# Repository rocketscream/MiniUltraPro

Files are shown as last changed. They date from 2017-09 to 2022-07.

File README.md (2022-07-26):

# Mini Ultra Pro
Mini Ultra Pro is an Arduino Compatible 32-bit ARM Cortex M0+ board that is suitable for ultra low power applications. During deep sleep mode, the board consumes only 16.5 uA (with the on-board serial flash chip and radio module in sleep mode). The board comes equipped with a 2Mbyte of serial flash and E19-900M20S2 LoRa radio module. Suitable application includes ultra low power wireless sensor network nodes that runs on Li-Ion/Pol batteries. On-board charger supports Li-Ion/Pol with proper load sharing capability to prolong the lifespan of the battery. The LoRa capable E19-900M20S2 radio module is able to achieve up to 8 km (in semi urban area, frequency of 915 MHz, transmission power of 20 dBm, LoRa spreading factor (SF) of 12, and coding rate (CR) of 4/5). A unique 64-bit MAC ID chip (Microchip's 24AA025E64) is available on-board to be used as DEVEUI in a LoRaWAN network.

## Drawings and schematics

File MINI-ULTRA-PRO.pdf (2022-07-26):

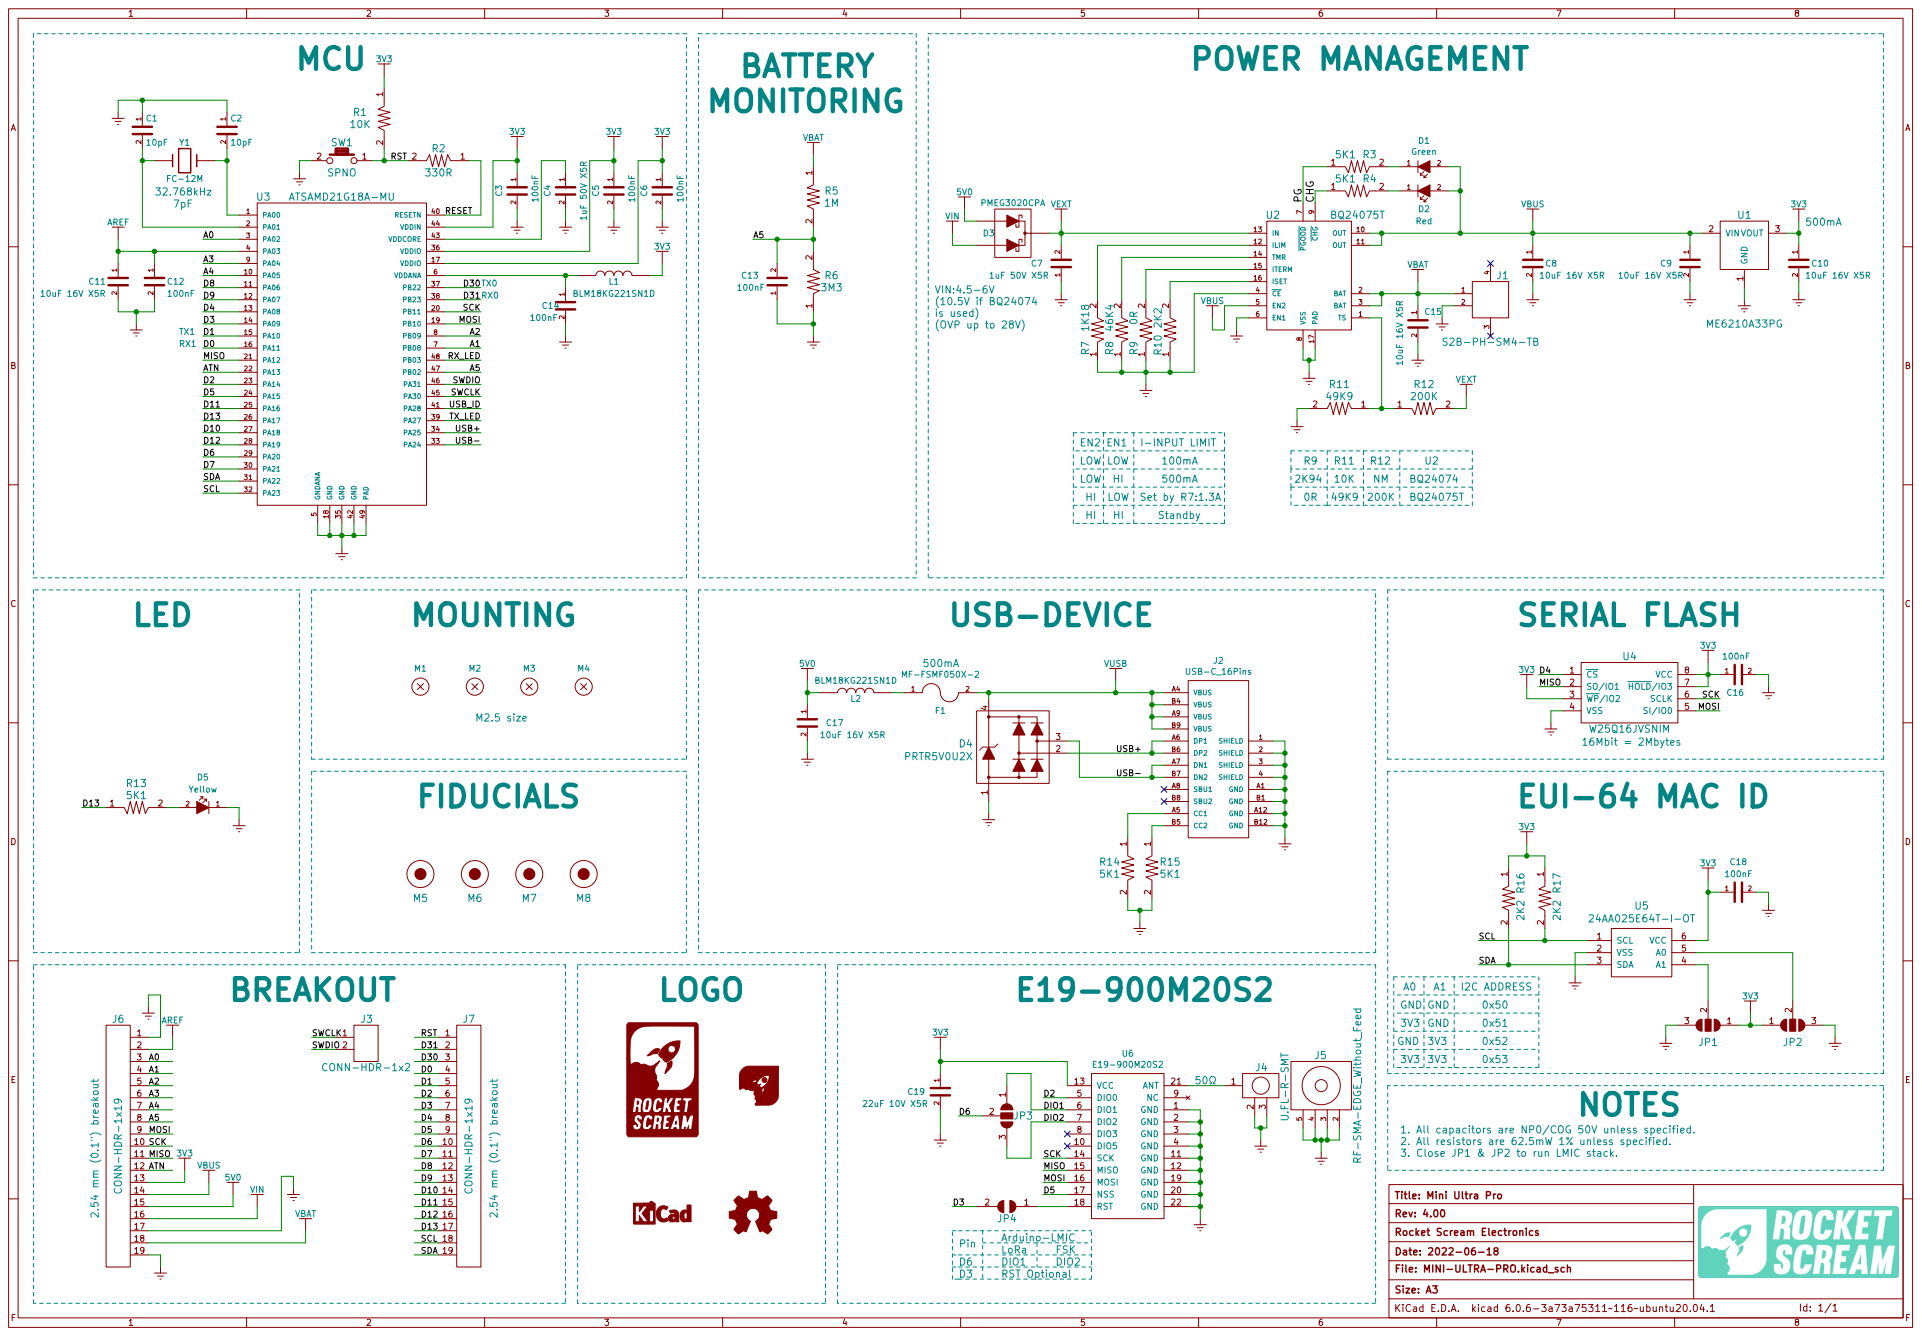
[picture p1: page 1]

1 2 C15 10uF 16V X5R TS 1 OUT 10 OUT 11 ILIM 12

A0 | GND

3V3 | | 0x51
3V3 GND | | 0x52

3. Close JP1 & JP2 to run LMIC stack. 3V3

1. All capacitors are NP0/COG 50V unless specified.
2. All resistors are 62.5mW 1% unless specified.

Id: 1/1 Title: Mini Ultra Pro
F Date: 2022-06-18 KiCad E.D.A. kicad 6.0.6-3a73a75311~116~ubuntu20.04.1 Rev: 4.00 Size: A3
File: MINI-ULTRA-PRO.kicad_sch Rocket Scream Electronics

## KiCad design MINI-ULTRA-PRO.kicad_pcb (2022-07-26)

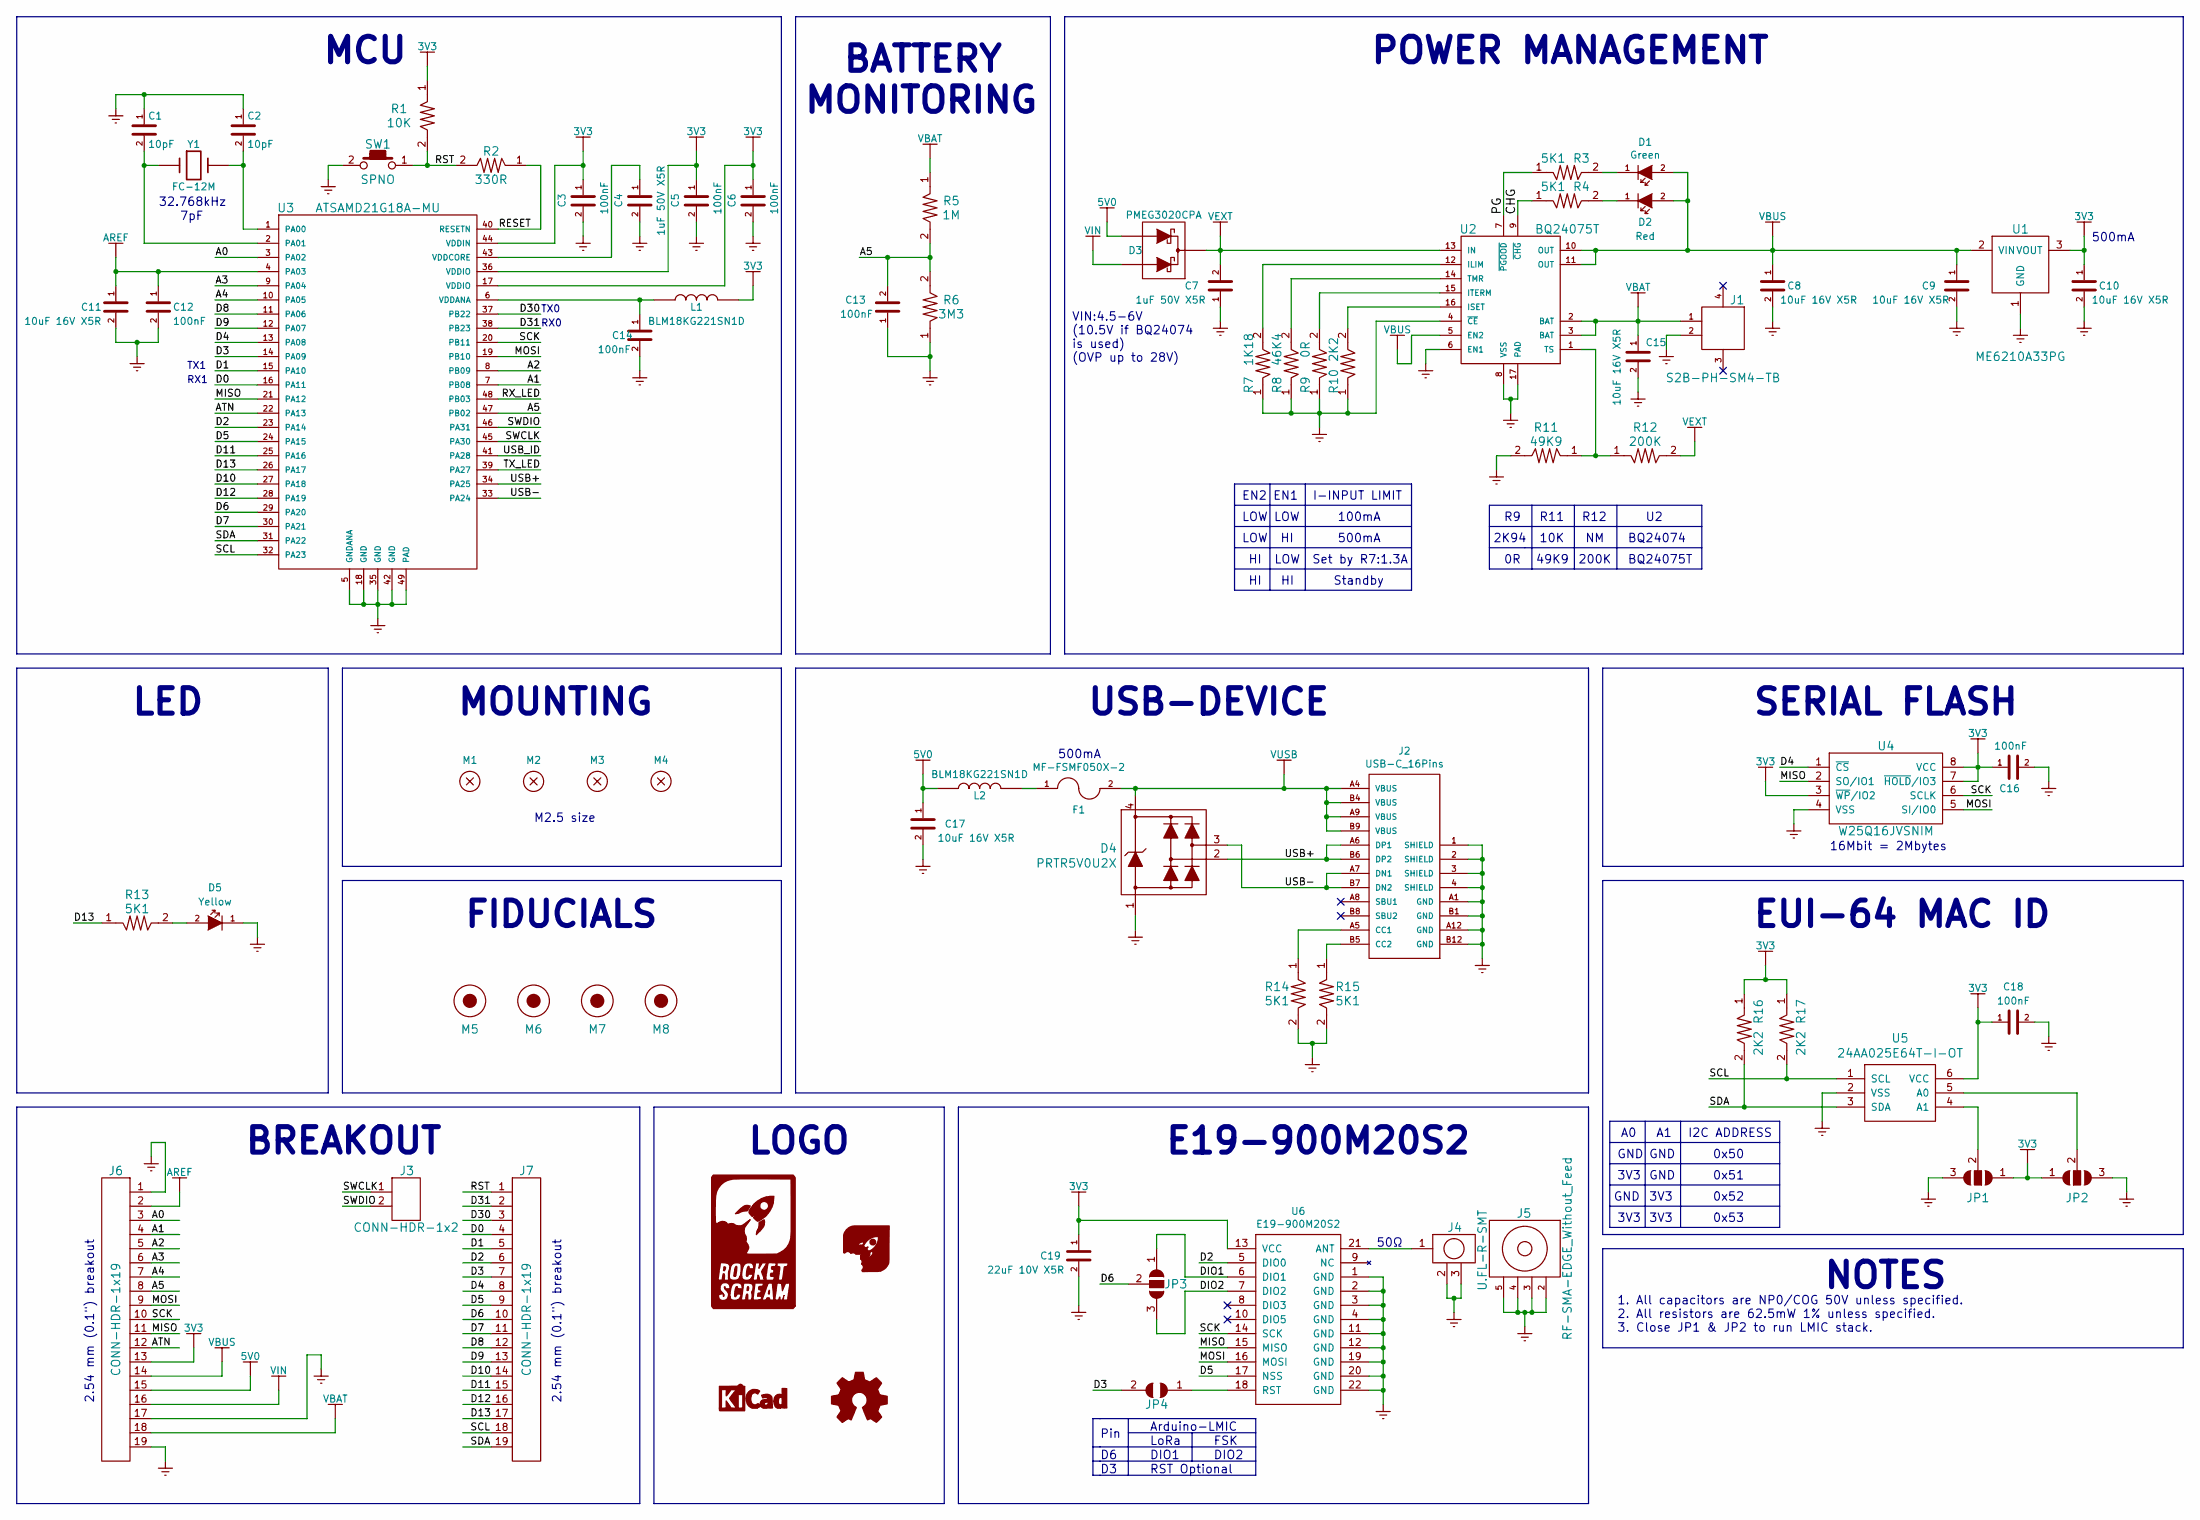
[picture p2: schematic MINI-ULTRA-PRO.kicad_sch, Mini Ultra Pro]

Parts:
C1, C2: 10pF; C_0603
C3, C5, C6, C12, C13, C14, C16, C18: 100nF; C_0603
C4, C7: 1uF 50V X5R; C_0603
C8, C9, C10, C11, C15, C17: 10uF 16V X5R; C_0603
C19: 22uF 10V X5R; C_0603
D1: Green; LED_0603
D2: Red; LED_0603
D3: PMEG3020CPA; SOT-1016
D4: PRTR5V0U2X; SOT-143B
D5: Yellow; LED_0603
F1: MF-FSMF050X-2; MF-FSMF
J1: S2B-PH-SM4-TB
J2: USB-C_16Pins; USB-TYPE-C-16PIN-SMD
J3: CONN-HDR-1x2; HDR_1x2_Pitch2.54mm_WithoutSilk
J4: U.FL-R-SMT; U.FL-R-SMT_Extended
J5: RF-SMA-EDGE_Without_Feed
J6, J7: CONN-HDR-1x19; HDR_1x19_Pitch2.54mm_WithoutSilk
JP1, JP2, JP3: JUMPER-2-WAY; JUMPER-2-WAY-SMD
JP4: JUMPER-1-WAY; JUMPER-1-WAY-SMD
L1, L2: BLM18KG221SN1D; I_0603
LOGO1: LOGO-ROCKET-SCREAM; LOGO-ROCKET-SCREAM_Vertical_Small
LOGO2: LOGO-ROCKET-SCREAM; LOGO-ROCKET-SCREAM_Without_Text_XXXSmall
LOGO3: LOGO-KICAD; LOGO-KICAD_XSmall
LOGO4: LOGO-OSHW; LOGO-OSHW_Small
M1, M2, M3, M4: MOUNT_HOLE; HOLE_NPTH_2.2MM
M5, M6, M7, M8: FIDUCIAL; FIDUCIAL-0.5MM_SQUARE
R1: 10K; R_0603
R2: 330R; R_0603
R3, R4, R13, R14, R15: 5K1; R_0603
R5: 1M; R_0603
R6: 3M3; R_0603
R7: 1K18; R_0603
R8: 46K4; R_0603
R9: 0R; R_0603
R10, R16, R17: 2K2; R_0603
R11: 49K9; R_0603
R12: 200K; R_0603
SW1: SPNO; TS-1086E-12
U1: ME6210A33PG; SOT-89_Microchip
U2: BQ24075T; QFN-16_3x3mm_TI
U3: ATSAMD21G18A-MU; QFN-48-1EP_7x7mm_Pitch0.5mm
U4: W25Q16JVSNIM; SOIC-8-N_8S1
U5: 24AA025E64T-I-OT; SOT-23-6
U6: E19-900M20S2
Y1: FC-12M; SC-20S

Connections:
3V3: C3.1, C5.1, C6.1, C10.1, C16.1, C18.1, C19.1, J6.13, JP1.1, JP2.1, L1.2, R1.1, R16.1, R17.1, U1.3 (VOUT), U3.17 (VDDIO), U3.36 (VDDIO), U3.44 (VDDIN), U4.3 (~WP/IO2), U4.7 (~HOLD/IO3), U4.8 (VCC), U5.6 (VCC), U6.13 (VCC)
5V0: C17.1, D3.1 (A), J6.15, L2.1
/A0: J6.3, U3.3 (PA02)
/A1: J6.4, U3.7 (PB08)
/A2: J6.5, U3.8 (PB09)
/A3: J6.6, U3.9 (PA04)
/A4: J6.7, U3.10 (PA05)
/A5: C13.2, J6.8, R5.2, R6.2, U3.47 (PB02)
/ATN: J6.12, U3.22 (PA13)
/CHG: R4.1, U2.9 (~CHG)
/D0: J7.4, U3.16 (PA11)
/D1: J7.5, U3.15 (PA10)
/D2: J7.6, U3.23 (PA14), U6.5 (DIO0)
/D3: J7.7, JP4.2, U3.14 (PA09)
/D4: J7.8, U3.13 (PA08), U4.1 (~CS)
/D5: J7.9, U3.24 (PA15), U6.17 (NSS)
/D6: J7.10, JP3.2, U3.29 (PA20)
/D7: J7.11, U3.30 (PA21)
/D8: J7.12, U3.11 (PA06)
/D9: J7.13, U3.12 (PA07)
/D10: J7.14, U3.27 (PA18)
/D11: J7.15, U3.25 (PA16)
/D12: J7.16, U3.28 (PA19)
/D13: J7.17, R13.1, U3.26 (PA17)
/D30: J7.3, U3.37 (PB22)
/D31: J7.2, U3.38 (PB23)
/DIO1: JP3.1, U6.6 (DIO1)
/DIO2: JP3.3, U6.7 (DIO2)
/MISO: J6.11, U3.21 (PA12), U4.2 (SO/IO1), U6.15 (MISO)
/MOSI: J6.9, U3.19 (PB10), U4.5 (SI/IO0), U6.16 (MOSI)
/PG: R3.1, U2.7 (~PGOOD)
/RESET: R2.1, U3.40 (RESETN)
/RST: J7.1, R1.2, R2.2, SW1.1
/RX_LED: U3.48 (PB03)
/SCK: J6.10, U3.20 (PB11), U4.6 (SCLK), U6.14 (SCK)
/SCL: J7.18, R17.2, U3.32 (PA23), U5.1 (SCL)
/SDA: J7.19, R16.2, U3.31 (PA22), U5.3 (SDA)
/SWCLK: J3.1, U3.45 (PA30)
/SWDIO: J3.2, U3.46 (PA31)
/TX_LED: U3.39 (PA27)
/USB+: D4.2, J2.A6 (DP1), J2.B6 (DP2), U3.34 (PA25)
/USB-: D4.3, J2.A7 (DN1), J2.B7 (DN2), U3.33 (PA24)
/USB_ID: U3.41 (PA28)
AREF: C11.1, C12.1, J6.2, U3.4 (PA03)
GND: C1.1, C2.1, C3.2, C4.2, C5.2, C6.2, C7.1, C8.2, C9.2, C10.2, C11.2, C12.2, C13.1, C14.2, C15.2, C16.2, C17.2, C18.2, C19.2, D4.1, D5.1 (K), J1.2, J2.1 (SHIELD), J2.2 (SHIELD), J2.3 (SHIELD), J2.4 (SHIELD), J2.A1 (GND), J2.A12 (GND), J2.B1 (GND), J2.B12 (GND), J4.2, J4.3, J5.2, J5.3, J5.4, J5.5, J6.1, J6.17, J6.19, JP1.3, JP2.3, R6.1, R7.1, R8.1, R9.1, R10.1, R11.2, R14.2, R15.2, SW1.2, U1.1 (GND), U2.4 (~CE), U2.6 (EN1), U2.8 (VSS), U2.17 (PAD), U3.5 (GNDANA), U3.18 (GND), U3.35 (GND), U3.42 (GND), U3.49 (PAD), U4.4 (VSS), U5.2 (VSS), U6.1 (GND), U6.2 (GND), U6.3 (GND), U6.4 (GND), U6.11 (GND), U6.12 (GND), U6.19 (GND), U6.20 (GND), U6.22 (GND)
unnamed: C1.2, U3.2 (PA01), Y1.1
unnamed: C2.2, U3.1 (PA00), Y1.2
unnamed: C4.1, U3.43 (VDDCORE)
unnamed: C14.1, L1.1, U3.6 (VDDANA)
unnamed: D1.1 (K), R3.2
unnamed: D2.1 (K), R4.2
unnamed: D5.2 (A), R13.2
unnamed: F1.1, L2.2
unnamed: J2.A5 (CC1), R14.1
unnamed: J2.B5 (CC2), R15.1
unnamed: J4.1, U6.21 (ANT)
unnamed: JP1.2, U5.4 (A1)
unnamed: JP2.2, U5.5 (A0)
unnamed: JP4.1, U6.18 (RST)
unnamed: R7.2, U2.12 (ILIM)
unnamed: R8.2, U2.14 (TMR)
unnamed: R9.2, U2.15 (ITERM)
unnamed: R10.2, U2.16 (ISET)
unnamed: R11.1, R12.1, U2.1 (TS)
VBAT: C15.1, J1.1, J6.18, R5.1, U2.2 (BAT), U2.3 (BAT)
VBUS: C8.1, C9.1, D1.2 (A), D2.2 (A), J6.14, U1.2 (VIN), U2.5 (EN2), U2.10 (OUT), U2.11 (OUT)
VEXT: C7.2, D3.3 (K), R12.2, U2.13 (IN)
VIN: D3.2 (A), J6.16
VUSB: D4.4, F1.2, J2.A4 (VBUS), J2.A9 (VBUS), J2.B4 (VBUS), J2.B9 (VBUS)

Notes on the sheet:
BQ24075T
49K9
FIDUCIALS
I-INPUT LIMIT
M2.5 size
500mA
POWER MANAGEMENT
0x53
R12
BREAKOUT
2.54 mm (0.1") breakout
BQ24074
TX0
MOUNTING
SERIAL FLASH
HI HI
2K94
GND
0x50
100mA
EUI-64 MAC ID
16Mbit = 2Mbytes
MCU
Set by R7:1.3A
LOW HI
Standby
RST Optional
Arduino-LMIC
0x52
HI LOW
LOGO
I2C ADDRESS
200K
E19-900M20S2
7pF
LED
RX0
1. All capacitors are NP0/COG 50V unless specified. 2. All resistors are 62.5mW 1% unless specified. 3. Close JP1 & JP2 to run LMIC stack.
3V3
VIN:4.5-6V (10.5V if BQ24074 is used) (OVP up to 28V)

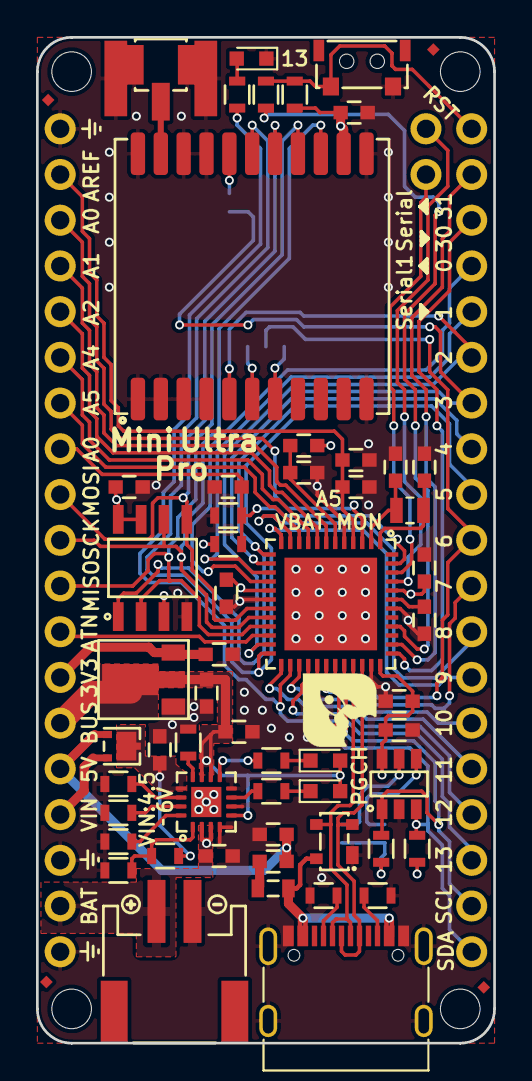
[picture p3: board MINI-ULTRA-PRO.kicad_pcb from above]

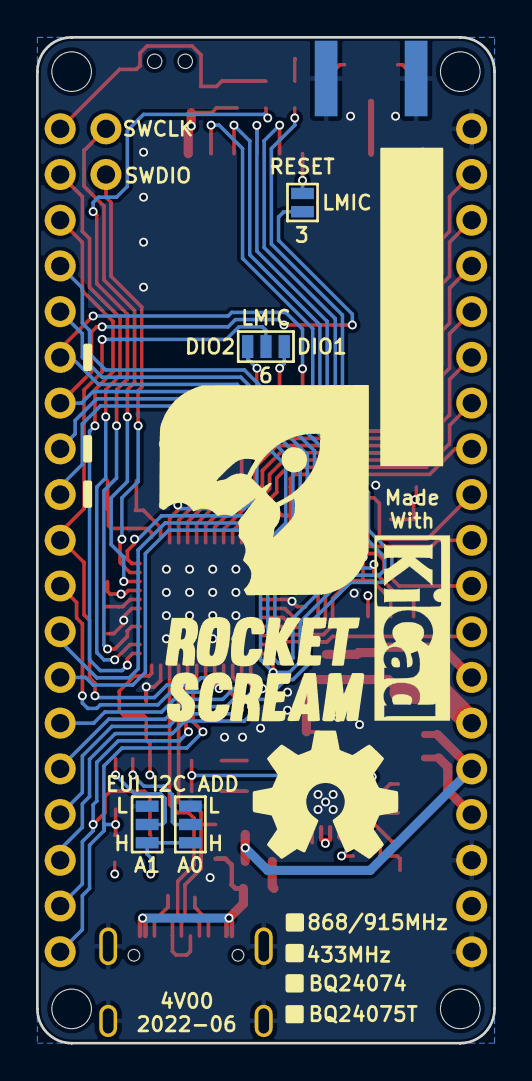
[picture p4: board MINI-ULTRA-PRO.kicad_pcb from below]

Board: 4 copper layers, 25.4 x 55.9 mm, 75 parts (8 on the bottom side), 66 nets.

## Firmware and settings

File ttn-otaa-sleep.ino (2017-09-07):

/*******************************************************************************
   Copyright (c) 2015 Thomas Telkamp and Matthijs Kooijman

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
   This example sends a valid LoRaWAN packet with payload "Hello,
   world!", using frequency and encryption settings matching those of
   the The Things Network.

   This uses OTAA (Over-the-air activation), where where a DevEUI and
   application key is configured, which are used in an over-the-air
   activation procedure where a DevAddr and session keys are
   assigned/generated for use with all further communication.

   Note: LoRaWAN per sub-band duty-cycle limitation is enforced (1% in
   g1, 0.1% in g2), but not the TTN fair usage policy (which is probably
   violated by this sketch when left running for longer)!

   To use this sketch, first register your application and device with
   the things network, to set or generate an AppEUI, DevEUI and AppKey.
   Multiple devices can use the same AppEUI, but each device has its own
   DevEUI and AppKey.

   Do not forget to define the radio type correctly in config.h.

 *******************************************************************************/

#include <lmic.h>
#include <hal/hal.h>
#include <SPI.h>
#include <Wire.h>
#include <RTCZero.h>
#include <SerialFlash.h>
#define EUI64_CHIP_ADDRESS 0x50
#define EUI64_MAC_ADDRESS 0xF8
#define EUI64_MAC_LENGTH 0x08
#define MAX_DATA_SIZE 2
#define Serial SerialUSB

RTCZero rtc;

// This EUI must be in little-endian format, so least-significant-byte
// first. When copying an EUI from ttnctl output, this means to reverse
// the bytes. For TTN issued EUIs the last bytes should be 0xD5, 0xB3,
// 0x70.
static const u1_t PROGMEM APPEUI[8] = { 0x00, 0x00, 0x00, 0x00, 0x00, 0xD5, 0xB3, 0x70 };
void os_getArtEui (u1_t* buf) {
  memcpy_P(buf, APPEUI, 8);
}

// This should also be in little endian format, see above.
u1_t DEVEUI[EUI64_MAC_LENGTH];
void os_getDevEui (u1_t* buf) {
  memcpy(buf, DEVEUI, EUI64_MAC_LENGTH);
}

// This key should be in big endian format (or, since it is not really a
// number but a block of memory, endianness does not really apply). In
// practice, a key taken from ttnctl can be copied as-is.
// The key shown here is the semtech default key.
static const u1_t PROGMEM APPKEY[16] = { 0x00, 0x00, 0x00, 0x00, 0x00, 0x00, 0x00, 0x00, 0x00, 0x00, 0x00, 0x00, 0x00, 0x00, 0x00, 0x00 };
void os_getDevKey (u1_t* buf) {
  memcpy_P(buf, APPKEY, 16);
}

static uint8_t data[MAX_DATA_SIZE];
static osjob_t sendjob;

// Schedule TX every this many seconds (might become longer due to duty
// cycle limitations).
const unsigned TX_INTERVAL = 60;

// Pin mapping
const lmic_pinmap lmic_pins = {
  .nss = 5,
  .rxtx = LMIC_UNUSED_PIN,
  .rst = 3,
  .dio = {2, 6, LMIC_UNUSED_PIN},
};

void onEvent (ev_t ev)
{
  Serial.print(os_getTime());
  Serial.print(": ");
  switch (ev) {
    case EV_SCAN_TIMEOUT:
      Serial.println(F("EV_SCAN_TIMEOUT"));
      break;
    case EV_BEACON_FOUND:
      Serial.println(F("EV_BEACON_FOUND"));
      break;
    case EV_BEACON_MISSED:
      Serial.println(F("EV_BEACON_MISSED"));
      break;
    case EV_BEACON_TRACKED:
      Serial.println(F("EV_BEACON_TRACKED"));
      break;
    case EV_JOINING:
      Serial.println(F("EV_JOINING"));
      break;
    case EV_JOINED:
      Serial.println(F("EV_JOINED"));

      // Disable link check validation (automatically enabled
      // during join, but not supported by TTN at this time).
      LMIC_setLinkCheckMode(0);
      break;
    case EV_RFU1:
      Serial.println(F("EV_RFU1"));
      break;
    case EV_JOIN_FAILED:
      Serial.println(F("EV_JOIN_FAILED"));
      break;
    case EV_REJOIN_FAILED:
      Serial.println(F("EV_REJOIN_FAILED"));
      break;
      break;
    case EV_TXCOMPLETE:
      Serial.println(F("EV_TXCOMPLETE (includes waiting for RX windows)"));
      if (LMIC.txrxFlags & TXRX_ACK)
        Serial.println(F("Received ack"));
      if (LMIC.dataLen) {
        Serial.println(F("Received "));
        Serial.println(LMIC.dataLen);
        Serial.println(F(" bytes of payload"));
      }
      // Ensure all debugging messages are sent before sleep
      Serial.flush();

      // Sleep for a period of TX_INTERVAL using single shot alarm
      rtc.setAlarmEpoch(rtc.getEpoch() + TX_INTERVAL);
      rtc.enableAlarm(rtc.MATCH_YYMMDDHHMMSS);
      rtc.attachInterrupt(alarmMatch);
      // USB port consumes extra current
      USBDevice.detach();
      // Enter sleep mode
      rtc.standbyMode();
      // Reinitialize USB for debugging
      USBDevice.init();
      USBDevice.attach();

      // Schedule next transmission to be immediately after this
      os_setTimedCallback(&sendjob, os_getTime() + sec2osticks(1), do_send);
      break;
    case EV_LOST_TSYNC:
      Serial.println(F("EV_LOST_TSYNC"));
      break;
    case EV_RESET:
      Serial.println(F("EV_RESET"));
      break;
    case EV_RXCOMPLETE:
      // data received in ping slot
      Serial.println(F("EV_RXCOMPLETE"));
      break;
    case EV_LINK_DEAD:
      Serial.println(F("EV_LINK_DEAD"));
      break;
    case EV_LINK_ALIVE:
      Serial.println(F("EV_LINK_ALIVE"));
      break;
    default:
      Serial.println(F("Unknown event"));
      break;
  }
}

void do_send(osjob_t* j)
{
  unsigned char counter;
  float batteryVoltage;
  int adcReading;
  int voltage;

  digitalWrite(LED_BUILTIN, HIGH);

  // Check if there is not a current TX/RX job running
  if (LMIC.opmode & OP_TXRXPEND)
  {
    Serial.println(F("OP_TXRXPEND, not sending"));
  }
  else
  {
    // ***** Battery monitor connection
    //
    // VBAT-----1M-----3M3-----GND
    //              | 
    //              ---0.1uF---GND
    //              |
    //              A5   

    adcReading = analogRead(A5);
    // Discard inaccurate 1st reading
    adcReading = 0;
    // Perform averaging
    for (counter = 10; counter > 0; counter--)
    {
      adcReading += analogRead(A5);
    }
    adcReading = adcReading / 10;
    // Convert to volts
    batteryVoltage = adcReading * (4.3 / 1023.0);

    Serial.print(F("Battery: "));
    Serial.print(batteryVoltage);
    Serial.println(F(" V"));

    // Pack float into int with 2 decimal point resolution
    voltage = batteryVoltage * 100;
    data[0] = voltage >> 8;
    data[1] = voltage;
    // Prepare upstream data transmission at the next possible time.
    LMIC_setTxData2(1, data, sizeof(data), 0);
    Serial.println(F("Packet queued"));
  }
  // Next TX is scheduled after TX_COMPLETE event.

  digitalWrite(LED_BUILTIN, LOW);
}

void setDevEui(unsigned char* buf)
{
  Wire.begin();
  Wire.beginTransmission(EUI64_CHIP_ADDRESS);
  Wire.write(EUI64_MAC_ADDRESS);
  Wire.endTransmission();
  Wire.requestFrom(EUI64_CHIP_ADDRESS, EUI64_MAC_LENGTH);

  // Format needs to be little endian (LSB...MSB)
  while (Wire.available())
  {
    *buf-- = Wire.read();
  }
}

void setup()
{
  int count;
  unsigned char pinNumber;

  // ***** Put unused pins into known state *****
  pinMode(0, INPUT_PULLUP);
  pinMode(1, INPUT_PULLUP);

  // D7-D13, A0(D14)-A5(D19), SDA(D20), SCL(D21), MISO(D22)
  for (pinNumber = 7; pinNumber <= 22; pinNumber++)
  {
    pinMode(pinNumber, INPUT_PULLUP);
  }
  // RX_LED (D25) & TX_LED (D26) (both LED not mounted on Mini Ultra Pro)
  pinMode(25, INPUT_PULLUP);
  pinMode(26, INPUT_PULLUP);
  // D30 (RX) & D31 (TX) of Serial
  pinMode(30, INPUT_PULLUP);
  pinMode(31, INPUT_PULLUP);
  // D34-D38 (EBDG Interface)
  for (pinNumber = 34; pinNumber <= 38; pinNumber++)
  {
    pinMode(pinNumber, INPUT_PULLUP);
  }
  // ***** End of unused pins state initialization *****

  pinMode(LED_BUILTIN, OUTPUT);

  setDevEui(&DEVEUI[EUI64_MAC_LENGTH - 1]);
  while (!Serial && millis() < 10000);
  Serial.begin(115200);
  Serial.println(F("Starting"));
  Serial.print(F("DEVEUI: "));

  for (count = EUI64_MAC_LENGTH; count > 0; count--)
  {
    Serial.print("0x");
    if (DEVEUI[count - 1] <= 0x0F) Serial.print("0");
    Serial.print(DEVEUI[count - 1], HEX);
    Serial.print(" ");
  }
  Serial.println();

  // Initialize serial flash
  SerialFlash.begin(4);
  // Put serial flash in sleep
  SerialFlash.sleep();

  // Initialize RTC
  rtc.begin();
  // Use RTC as a second timer instead of calendar
  rtc.setEpoch(0);

  // LMIC init
  os_init();
  // Reset the MAC state. Session and pending data transfers will be discarded.
  LMIC_reset();
  LMIC_setClockError(MAX_CLOCK_ERROR * 1 / 100);

  // Start job (sending automatically starts OTAA too)
  do_send(&sendjob);
}

void loop() {
  os_runloop_once();
}

void alarmMatch()
{

}

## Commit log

2016-02-22 Revision 0.20
    [MINI-ULTRA-PRO.kicad_pcb, MINI-ULTRA-PRO.sch]
2017-07-19 Version 0.40
    [MINI-ULTRA-PRO.kicad_pcb, MINI-ULTRA-PRO.sch]
2017-09-07 Fix LMIC_UNUSED_PIN on D7 in LoRa mode
    [ttn-otaa-sleep.ino]
2017-09-07 Corrected EUI-64 sequence printing on USB port during power up
    [ttn-otaa-sleep.ino]
2018-02-21 Version 0.50 - V3
    [MINI-ULTRA-PRO.kicad_pcb, MINI-ULTRA-PRO.sch]
2018-09-04 Remove enclosure files for Mini Ultra LoRaWAN
    [RocketScream_MiniUltraLoRaWAN_bottom.stl, RocketScream_MiniUltraLoRaWAN_bottom_-_no_gasket.stl, RocketScream_MiniUltraLoRaWAN_gasket.stl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]
2022-07-26 Remove KiCad v5 files
    [MINI-ULTRA-PRO.sch]
2022-07-26 Version 4.00 - V4
    [MINI-ULTRA-PRO.kicad_pcb, MINI-ULTRA-PRO.kicad_sch]
2022-07-26 Remove KiCad v5 footprints
